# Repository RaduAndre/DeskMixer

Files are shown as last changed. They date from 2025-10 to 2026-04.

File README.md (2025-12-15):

# DeskMixer 🎛️

<div align="center">

A **low latency** physical volume mixer with programmable buttons for Windows, inspired by [Deej](https://github.com/omriharel/deej).

**Control your audio with near-instant response and automate actions with real hardware - fully scalable to your needs!**

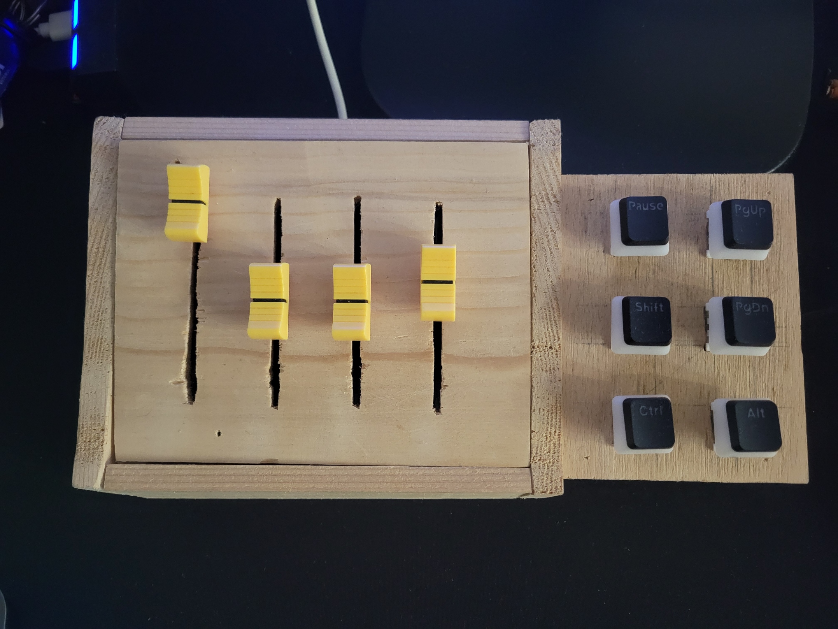
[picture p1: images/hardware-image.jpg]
DeskMixer Hardware


[Features](#-features) • [Hardware](#-hardware) • [Installation](#-installation) • [Configuration](#-configuration) • [Building](#-building-from-source)

</div>

---

## 🚀 Get Started 

**For Windows users, the simplest way to get up and running is with the pre-compiled executable!**

1.  **Download:** Go to the [**Releases Page**](/RaduAndre/DeskMixer/releases) and download the latest `DeskMixer.exe` file. (no instalation needed)
2. **Configure:** Follow the steps in the [Configuration](#-configuration) section to bind your sliders and program your buttons!

---

## 📸 Gallery

### Modern Software Interface

DeskMixer features a sleek, modern interface with a dark theme and smooth animations designed for intuitive hardware control.

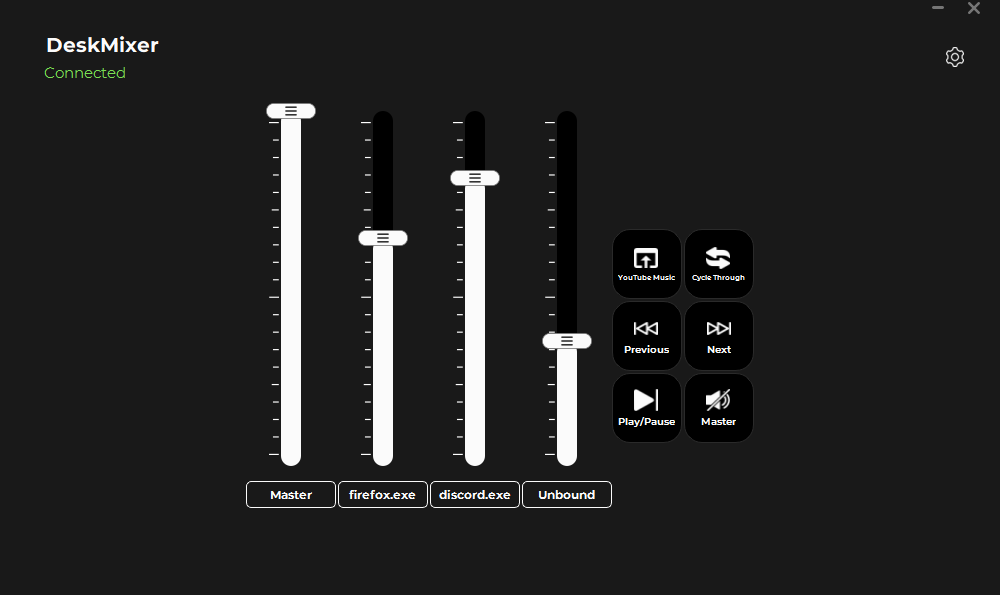
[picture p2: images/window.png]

*Clean, modern interface with volume sliders and programmable action buttons*

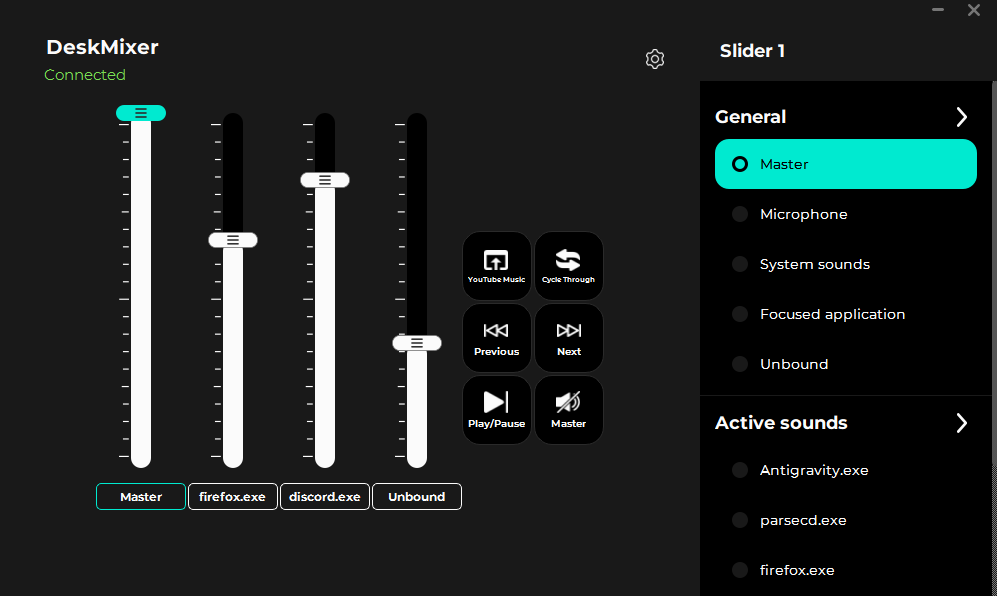
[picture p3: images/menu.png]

*Sliding configuration menu for easy customization*

#### Interface Features

**Visual Design:**
- 🎨 **Modern Interface**: Premium glassmorphic design with **customizable accent colors** and animations
- 🪟 **Frameless Window**: Custom title bar with drag-to-move functionality
- 📐 **Scalable Layout**: Automatically adapts to any number of sliders and buttons
- ✨ **Smooth Animations**: Fluid transitions and visual feedback for all interactions

**Volume Sliders:**
- 🎛️ **Visual Scale Indicators**: Each slider displays a scale icon showing the full range
- 🏷️ **Smart Labels**: Automatically display bound applications (e.g., "Master + Spotify")
- 💚 **Hardware Sync**: Sliders animate smoothly when adjusted via hardware with green highlight feedback
- 🔄 **Drag-and-Drop Reordering**: Rearrange sliders to match your preferred layout
- 🖱️ **Click-to-Configure**: Click any slider to open its configuration menu

**Action Buttons:**
- 🎮 **Customizable Grid**: Arrange buttons in any grid size (rows × columns)
- 🔵 **Active State Indicators**: Blue highlight shows which buttons are configured
- ⚡ **Hardware Feedback**: Buttons flash when pressed on the physical device
- 🔄 **Drag-and-Drop**: Reorder buttons including empty placeholder positions
- 📝 **Dynamic Labels**: Button text adjusts to show the configured action

**Configuration Menu:**
- 📱 **Sliding Panel**: Smooth slide-in menu from the right side
- 🎯 **Context-Sensitive**: Different menus for sliders, buttons, and settings
- 🔍 **Live Search**: Browse and add applications with file picker integration
- 📋 **Expandable Sections**: Organized categories with collapsible headers
- ✅ **Visual Selection**: Active bindings highlighted with checkmarks

**Settings & Customization:**
- ⚙️ **General Settings**: Start hidden, Windows startup integration, slider sampling modes
- 📐 **Layout Controls**: Configure button grid dimensions (R×C)
- 🔄 **Reorder Modes**: Toggle swap modes for buttons or sliders independently
- 📊 **Slider Sampling**: Choose between Soft, Normal, or Hard sensitivity modes
- ℹ️ **Version Display**: Build version shown at bottom of settings menu

**Hardware Integration:**
- 🔌 **Real-time Sync**: Slider positions update instantly from hardware movements
- 🎯 **Button Press Feedback**: Visual flash confirms hardware button presses
- 🔄 **Bidirectional Control**: Changes sync between hardware and software
- 🚫 **Read-only Sliders**: UI sliders display-only to prevent conflicts with hardware control

### DIY Hardware Build
DeskMixer Hardware
*A functional, handcrafted build - proving that professional results don't require a professional workshop!*

---

## ✨ Features

DeskMixer takes physical volume control and supercharges it with macro-like button actions.

### Volume Control
- ⚡ **Low Latency**: Optimized for near-instant response (~10-20ms) with 115200 baud serial communication
- 🎛️ **Physical Sliders**: Control individual application volumes with real hardware sliders
- 📊 **Scalable Design**: Add as many sliders as you need - the software adapts automatically
- 🔊 **Flexible Targets**: Control master volume, microphone, system sounds, or individual apps
- 🎚️ **Adjustable Sensitivity**: Choose between Instant, Responsive, Soft, Normal, or Hard sampling modes
- 💾 **Persistent Settings**: Your configuration is saved between sessions

### Button Actions
- ⌨️ **Custom Keybinds**: Map any keyboard shortcut to physical buttons
- 🎮 **Media Controls**: Play/pause, next/previous track, seek forward/backward
- 🔇 **Mute Controls**: Instant mute/unmute for system, microphone, or specific applications
- 🔀 **Audio Switching**: Switch between audio output devices with a button press
- 🚀 **App Launcher**: Launch or focus applications instantly

### System Integration
- 🪟 **System Tray**: Runs minimized with quick access
- 🔌 **Auto-Detection**: Automatic serial port detection
- 🔄 **Hot-Reload**: Configuration updates in real-time
- 🎯 **Focus Tracking**: Optional control of currently active application

---

## 🎛️ Volume Targets

The software supports multiple volume control modes:

| Target | Description | Use Case |
|---|---|---|
| 🔊 **Master** | System master volume | Overall volume control |
| 🎤 **Microphone** | Default microphone input | Quick mic adjustments |
| 🔔 **System Sounds** | Windows notification sounds | Silence those pings! |
| ⭐ **Current Application** | Currently focused app | Dynamic control of active app |
| 🎵 **Individual Apps** | Specific applications | Dedicated controls (Spotify, Discord, etc.) |
| ❔ **Unbound** | No assignment | Flexible unassigned slider |
| ❌ **None** | Disabled | Slider inactive |

**Note:** The application list updates automatically based on running audio applications. **The UI scales to accommodate any number of slider bindings you create!**

---

## 🎮 Button Actions

### Media Controls
- ⏯️ **Play/Pause**: Toggle media playback
- ⏭️ **Next Track**: Skip to next media track  
- ⏮️ **Previous Track**: Go to previous media track
- ⏩ **Seek Forward**: Jump forward in current media
- ⏪ **Seek Backward**: Jump backward in current media

### Audio Controls
- 🔊 **Volume Up**: Increase system volume
- 🔉 **Volume Down**: Decrease system volume
- 🔇 **Mute**: Toggle mute for system, microphone, or specific application
- 🔀 **Switch Audio Output**: Switch between available audio output devices*

### Advanced Actions
- ⌨️ **Custom Keybind**: Execute any keyboard shortcut (see [KEYBIND_EXAMPLES.md](KEYBIND_EXAMPLES.md))
- 🚀 **Launch App**: Start or focus specific applications

**Pro Tip:** Combine button actions with specific application targets for powerful workflows. For example:
- Mute Discord specifically with one button
- Launch Spotify and set volume to 50% with another
- Send custom shortcuts to specific apps

**The button configuration UI scales dynamically - add as many buttons as your microcontroller has pins!**

---

## 🔧 Hardware

### Required Components
- **Microcontroller**: ESP32 or compatible Arduino board
- **Sliders**: 4x 10kΩ linear potentiometers (scalable to more)
- **Buttons**: 6x push buttons (scalable to more)
- **Connection**: PCB or breadboard
- **Cable**: USB cable for serial communication

### Default Pin Configuration
You can modify these in the Arduino sketch to match your build:

**Sliders:**
- GPIO 33, 32, 35, 34

**Buttons:**
- GPIO 27, 25, 14, 26, 12, 13

### Expanding Your Build
Want more controls? Simply:
1. Add more potentiometers/buttons to your hardware
2. Update the pin configuration in `arduino/DeskMixer/DeskMixer.ino`
3. Upload the modified firmware
4. The DeskMixer software will automatically detect and configure the new inputs!

### Circuit Explanation

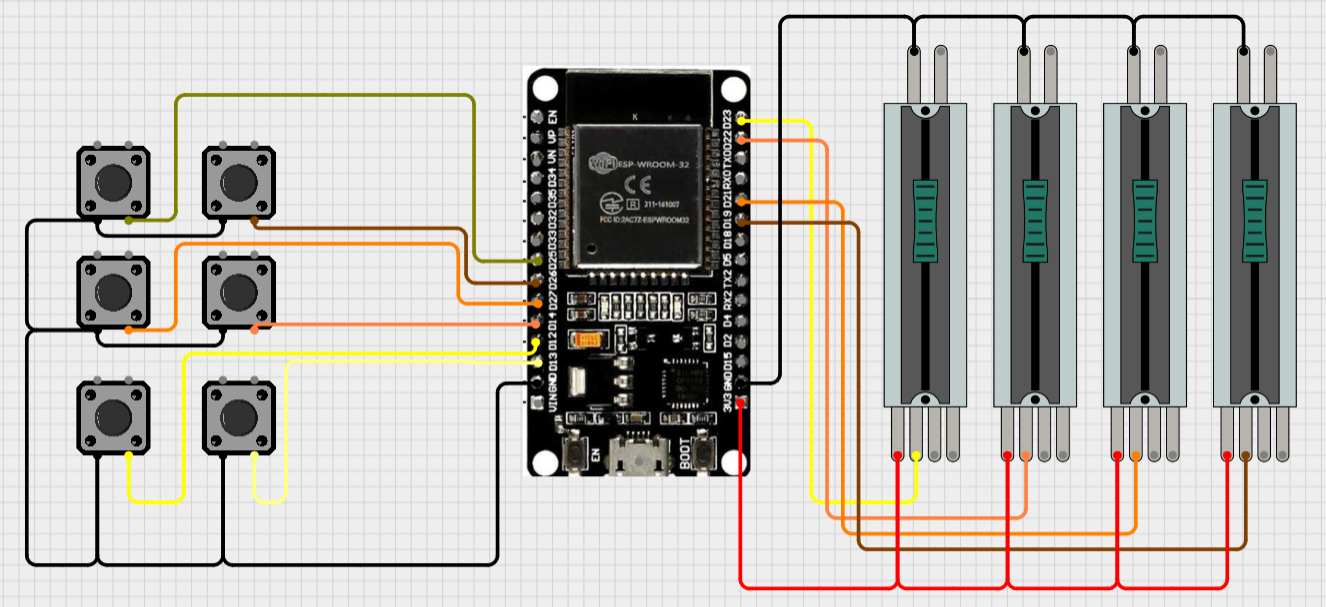
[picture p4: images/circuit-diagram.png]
Circuit Diagram

*Wiring diagram showing connections between ESP32, potentiometers, and buttons*

#### Understanding the Circuit

The DeskMixer circuit consists of three main components working together:

**Power Distribution:**
- The ESP32 is powered via USB connection to your computer
- All components share a common ground (GND) connection
- The 3.3V pin from the ESP32 powers the potentiometers

**Potentiometer Connections (Volume Sliders):**
Each potentiometer has three pins:
- **Left pin**: Connected to GND (ground)
- **Middle pin (wiper)**: Connected to ESP32 analog input pins (GPIO 33, 32, 35, 34)
- **Right pin**: Connected to 3.3V power

As you move the slider, the middle pin voltage varies between 0V and 3.3V, which the ESP32 reads as analog values (0-1024). The software then maps these values to volume levels (0-100%).

**Button Connections:**
Each button uses a simple pull-down configuration:
- **One side**: Connected to ESP32 digital input pins (GPIO 27, 25, 14, 26, 12, 13)
- **Other side**: Connected to GND (ground)
- **Internal pull-up resistor**: Enabled in firmware (button reads HIGH when not pressed, LOW when pressed)

**Color Coding in Diagram:**
- **Black**: Ground connections
- **Red**: 3.3V power connections
- **Yellow/Orange/Blue**: Signal wires to ESP32 GPIO pins

#### Important Notes

⚠️ **Analog Pin Limitations**: On ESP32, not all pins support analog reading. Use only ADC1 pins (GPIO 32-39) for potentiometers. Avoid GPIO 25 and 26 for analog input as they're DAC pins.

⚠️ **Voltage Levels**: ESP32 GPIO pins are 3.3V tolerant. Never connect 5V directly to any GPIO pin.

💡 **Wire Gauge**: Use 22-24 AWG wire for connections. Solid core wire works well for breadboard prototyping, while stranded wire is better for the final build.

💡 **Debouncing**: The firmware includes software debouncing for buttons to prevent false triggers. No additional hardware debouncing (capacitors) is needed.

### 3D Models & PCB Files
> **Coming Soon**: 3D printable enclosure models and Gerber files for PCB manufacturing will be added in future updates!

---

## 📦 Installation

### Option 1: Pre-built Executable (Easiest)

1. Download `DeskMixer.exe` from the [Releases](https://github.com/RaduAndre/DeskMixer/releases) page.
2. Run the executable

### Option 2: Run from Source

**Requirements:**
- Python 3.13+
- Arduino IDE
- ESP32 board or compatible Arduino

**Steps:**

1. Clone the repository:
```bash
git clone https://github.com/RaduAndre/DeskMixer.git
cd DeskMixer/src
```

2. Install dependencies:
```bash
pip install -r requirements.txt
```

3. Run the application:
```bash
python main.py
```

### Upload Firmware to Arduino

1. Open `arduino/DeskMixer/DeskMixer.ino` in Arduino IDE
2. Select your board (ESP32) and COM port
3. Upload the sketch
4. The firmware will automatically communicate with DeskMixer

---

## ⚙️ Configuration

### First-Time Setup

1. **Launch DeskMixer**
2. **Connect Hardware**: The application will automatically detect your Arduino's serial port
3. **Configure Sliders**: 
   - Click on any slider to open the configuration menu
   - Select from General options (Master, Microphone, System sounds, Focused application, Unbound)
   - Or choose from Active sounds (currently running applications)
   - Or add custom applications via the search function
   - Multiple applications can be bound to the same slider
4. **Configure Buttons**:
   - Click on any button to open the action menu
   - Select from Media Controls (Play/Pause, Next, Previous, etc.)
   - Configure Mute actions with specific targets
   - Set up custom Keybinds or Launch app actions
   - Changes save automatically

### Slider Configuration

**Binding Options:**
- **General Targets**: Master volume, Microphone, System sounds, Focused application, Unbound
- **Active Sounds**: Dynamically detected running applications with audio
- **Custom Applications**: Add any application via name search or file browser
- **Multiple Bindings**: Bind multiple applications to a single slider for grouped control
- **Smart Labels**: Slider labels automatically update to show all bound applications

**Configuration Menu:**
- Click any slider to open its dedicated configuration menu
- Expandable sections organize options by category
- Active bindings show checkmarks for easy identification
- Right-click custom applications to delete them from the list
- Browse for .exe or .lnk files to add new applications

### Button Configuration

**Available Actions:**

*Media Controls:*
- Play/Pause, Previous, Next
- Volume up/down
- Seek backward/forward

*Advanced Actions:*
- **Mute**: Choose target (Master, Microphone, System sounds, Focused application)
- **Switch Audio Output**: Cycle through devices or select specific output (Speakers, Headphones)
- **Keybind**: Enter custom keyboard shortcuts (see [KEYBIND_EXAMPLES.md](KEYBIND_EXAMPLES.md))
- **Launch app**: Browse and select applications to launch or focus

**Configuration Menu:**
- Click any button to open its action menu
- Expandable items reveal sub-options (e.g., Mute → Master/Microphone/etc.)
- Input fields for Keybind and Launch app actions
- File browser integration for selecting applications
- Active action highlighted with blue indicator

### Layout Customization

**Button Grid:**
- Open Settings menu (gear icon)
- Navigate to Layout → Grid Size
- Enter desired Rows (R) and Columns (C)
- Grid automatically validates against available buttons
- Invalid dimensions flash red with error feedback

**Reordering Elements:**
- Open Settings → Layout → Reorder Elements
- Select "Swap Buttons" or "Swap Sliders" to enter reorder mode
- Drag and drop elements to rearrange them
- Supports sparse layouts (buttons can occupy any grid position)
- Click the reorder option again to exit reorder mode

### Settings Menu

Access via the gear icon in the top-right corner:

**General:**
- **Start Hidden (on tray)**: Launch minimized to system tray
- **Start on Windows startup**: Automatically launch with Windows
- **Slider Sampling**: Adjust hardware response sensitivity
  - **Instant**: Zero-latency mode - no smoothing for immediate response
  - **Responsive**: Minimal smoothing - very fast with slight stabilization
  - **Soft**: Light averaging - balanced response (5 samples)
  - **Normal**: Moderate averaging - smooth control (10 samples)
  - **Hard**: Heavy averaging - very smooth, slower response (20 samples)

**Layout:**
- **Grid Size**: Configure button grid dimensions
- **Accent Color**: Customize the UI with 'Default' (Teal) or any custom color via the picker
- **Reorder Elements**: Enable drag-and-drop for buttons or sliders

### System Tray
- **Double-click** tray icon: Show/hide main window
- **Right-click** tray icon: Quick actions menu
- Window automatically minimizes to tray when closed

---

## 🏗️ Building from Source

Create your own executable using either method:

### PyInstaller (Faster)
```bash
cd src
python build_app.py
```

### Nuitka (More Optimized)
```bash
cd src
python build_nuitka.py
```

Built executables will appear in `src/build/dist/`

---

## 🎨 About the Hardware Build

The device shown in the gallery was handcrafted with basic tools and materials - no fancy workshop required! It's a testament that functional, effective hardware doesn't need to be professionally manufactured. The beauty of this project is in its functionality and the satisfaction of building something yourself.

**DIY Philosophy:** This project embraces the maker spirit - it's about creating tools that work for YOU, not winning beauty contests. If it controls your volume and makes your workflow better, it's perfect.

---

## 🛠️ Customization & Scalability

DeskMixer is designed to grow with your needs:

### Hardware Scaling
- **Start small**: 2 sliders and 2 buttons  
- **Go big**: 16+ sliders and 20+ buttons
- **Mix it up**: Combine sliders, buttons, rotary encoders, or other inputs

The software automatically adapts to whatever hardware configuration you define in the Arduino firmware!

### Software Flexibility
- Configure targets per-slider/button
- Create complex automation chains
- Save multiple profiles (future feature)

---

## 📝 Keybind Examples

For comprehensive keybind examples and syntax, see [KEYBIND_EXAMPLES.md](KEYBIND_EXAMPLES.md)

---

## 🤝 Contributing

Contributions are welcome! Whether it's:
- 🐛 Bug reports
- 💡 Feature suggestions  
- 📝 Documentation improvements
- 🔧 Code contributions
- 📸 Sharing your build

Feel free to open an issue or submit a pull request!

---

## 📄 License

This project is open source. Check the [LICENSE](LICENSE) file for details.

---

## 🙏 Acknowledgments

- Inspired by [Deej](https://github.com/omriharel/deej) by Omri Harel
- Built with passion for makers and tinkerers everywhere
- Special thanks to everyone who builds DIY hardware and shares their projects!

---

## 📞 Support

- **Issues**: [GitHub Issues](https://github.com/RaduAndre/DeskMixer/issues)
- **Discussions**: [GitHub Discussions](https://github.com/RaduAndre/DeskMixer/discussions)

---

<div align="center">

**Made with 🎛️ by makers, for makers**

Star ⭐ this repo if you find it useful! You can also support further development [buying me a Coffe ☕](https://ko-fi.com/andreiradu).

</div>

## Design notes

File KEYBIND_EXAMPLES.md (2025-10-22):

# Keybind Examples

When using the "Keybind (Custom)" action, you can specify various key combinations:

## Single Keys
- `a`, `b`, `c`, etc.
- `space`
- `enter`
- `esc`

## Media Keys
- `play/pause media`
- `next track`
- `previous track`
- `volume up`
- `volume down`

## Key Combinations
- `ctrl+c` - Copy
- `ctrl+v` - Paste
- `alt+tab` - Switch windows
- `win+d` - Show desktop
- `ctrl+shift+esc` - Task Manager

## Special Keys
- `f1` through `f12` - Function keys
- `home`, `end`, `page up`, `page down`
- `up`, `down`, `left`, `right` - Arrow keys
- `backspace`, `delete`, `tab`

## Multiple Keys in Sequence
Use a list format: `["ctrl+c", "ctrl+v"]` to press multiple keys in order

Note: Requires 'keyboard' module to be installed for keybind functionality.

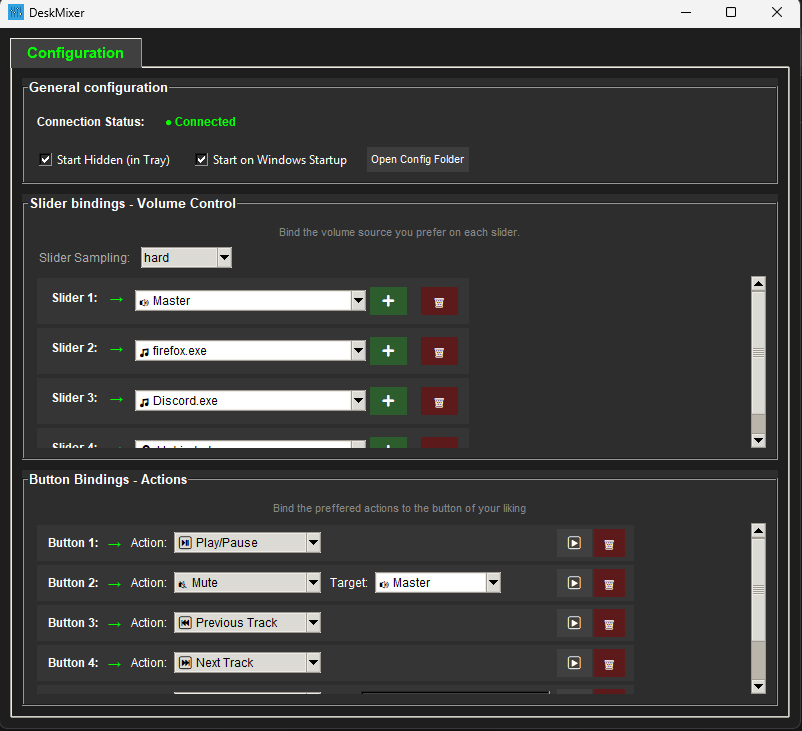
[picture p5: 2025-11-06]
images/ui-screenshot.png

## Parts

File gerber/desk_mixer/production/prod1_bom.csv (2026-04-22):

Designator | Footprint | Quantity | Value | LCSC Part #
C1, C14, C15, C16, C17, C18, C19, C2, C21, C3, C4, C6, C9 | C0603 | 13 | 100n | C14663
C10, C11 | C0603 | 2 | 10p | C1634
C12, C13 | C0805 | 2 | 22u | C602037
C20 | CAP-SMD_BD10.0-L10.3-W10.3-FD | 1 | BXJ 10V1000uF | C165632
C5 | C0603 | 1 | 10u | C19702
C7, C8 | C0603 | 2 | 1uF | C15849
CN1, CN2 | CONN-SMD_4P-P1.00_SM04B-SRSS-TB-LF-SN | 2 | SM04B-SRSS-TB (LF)(SN) | C160404
D1 | screen | 1 | ~
D2 | SMA_L4.2-W2.6-LS5.0-RD_1 | 1 | SS14 | C2480
KAL1, KAL2, KAL3, KAL4, KAL5, KAL6 | TH_L10.9-W5.9-CPG151101S11-2 | 6 | CPG151101S11-2_C49352235 | C49352235
L1 | L0603 | 1 | Ferritebead | C85831
LED1, LED10, LED11, LED12, LED13, LED14, LED15, LED16, LED17, LED18, LED19, LED2, LED20, LED21, LED22, LED23, LED24, LED25, LED26, LED27, LED28, LED29, LED3, LED30, LED31, LED32, LED33, LED34, LED35, LED36, LED37, LED38, LED39, LED4, LED40, LED41, LED42, LED43, LED44, LED45, LED46, LED5, LED6, LED7, LED8, LED9 | LED-SMD_4P-L3.7-W3.5-P1.75-BR-SK6812MINI | 46 | SK6812MINI | C2886570
LED47 | LED0805-R-RD_RED | 1 | Red led | C19171391
R1, R2 | R0603 | 2 | 5.1k | C2907044
R3 | R0603 | 1 | 10k | C98220
R4, R5 | R0805 | 2 | 1.5k | C336856
S1, S2, S3, S4, S5 | b103 | 5 | ~
SW1 | SW-SMD_MST-12D18G4-SPDT-SLIDE-SWITCH | 1 | MST-12D18G4 SPDT SLIDE SWITCH | C49023767
U1 | LQFP-48_L7.0-W7.0-P0.50-LS9.0-BL | 1 | STM32F103C8T6 | C8734
U2 | HDR-TH_4P-P2.54-V-M-1 | 1 | 2.54-1*4 | C5116483
U3 | SOT-223-3_L6.5-W3.4-P2.30-LS7.0-BR | 1 | AMS1117-3.3 | C6186
U4 | SOP-8_L5.3-W5.3-P1.27-LS8.0-BL | 1 | GD25Q64ESIG | C2685734
U5 | SOIC-14_L8.7-W3.9-P1.27-LS6.0-BL | 1 | SN74AHCT125DR | C155176
USB1 | USB-SMD-LIGHTNING_USB-PG | 1 | USB-PG 10PIN 040 | C2858295
X1 | CRYSTAL-SMD_4P-L3.2-W2.5-BL | 1 | X322516MMB4SI | C112972

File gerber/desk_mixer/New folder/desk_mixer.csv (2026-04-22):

Reference | Qty | Value | DNP | Exclude from BOM | Exclude from Board | Footprint | Datasheet | LCSC Part
C1,C2,C3,C4,C6,C9,C14,C15,C16,C17,C18,C19,C21 | 13 | 100n |  |  |  | LCSC_Library:C0603 | https://lcsc.com/product-detail/Multilayer-Ceramic-Capacitors-MLCC-SMD-SMT_100nF-104-10-50V_C14663.html | C14663
C5 | 1 | 10u |  |  |  | LCSC_Library:C0603 | https://lcsc.com/product-detail/Multilayer-Ceramic-Capacitors-MLCC-SMD-SMT_SAMSUNG_CL10A106KP8NNNC_10uF-106-10-10V_C19702.html | C19702
C7,C8 | 2 | 1uF |  |  |  | LCSC_Library:C0603 | https://lcsc.com/product-detail/Multilayer-Ceramic-Capacitors-MLCC-SMD-SMT_SAMSUNG_CL10A105KB8NNNC_1uF-105-10-50V_C15849.html | C15849
C10,C11 | 2 | 10p |  |  |  | LCSC_Library:C0603 | https://lcsc.com/product-detail/Multilayer-Ceramic-Capacitors-MLCC-SMD-SMT_SAMSUNG_CL10C100JB8NNNC_10pF-100-5-50V_C1634.html | C1634
C12,C13 | 2 | 22u |  |  |  | LCSC_Library:C0805 | https://lcsc.com/product-detail/Multilayer-Ceramic-Capacitors-MLCC-SMD-SMT_Samsung-Electro-Mechanics-CL21A226MAYNNNE_C602037.html | C602037
C20 | 1 | 1000uF |  |  |  | LCSC_Library:CAP-TH_BD12.5-P5.00-D0.6-FD | https://lcsc.com/product-detail/Aluminum-Electrolytic-Capacitors-Leaded_Rubycon_35YXJ1000M12-5X20_1000uF-35V_C88743.html | C88743
CN1,CN2 | 2 | SM04B-SRSS-TB (LF)(SN) |  |  |  | LCSC_Library:CONN-SMD_4P-P1.00_SM04B-SRSS-TB-LF-SN | https://lcsc.com/product-detail/Others_JST-Sales-America__JST-Sales-America-SM04B-SRSS-TB-LF-SN_C160404.html | C160404
D1 | 1 | ~ |  |  |  | sliding_potentiometer_b103:screen
D2 | 1 | SS14 |  |  |  | LCSC_Library:SMA_L4.2-W2.6-LS5.0-RD_1 | https://lcsc.com/product-detail/Schottky-Barrier-Diodes-SBD_SS14_C2480.html | C2480
Kal1,Kal2,Kal3,Kal4,Kal5,Kal6 | 6 | CPG151101S11-2_C49352235 |  |  |  | LCSC_Library:TH_L10.9-W5.9-CPG151101S11-2 |  | C49352235
L1 | 1 | Ferritebead |  |  |  | LCSC_Library:L0603 | https://lcsc.com/product-detail/Ferrite-Beads-And-Chips_muRata_BLM18KG121TN1D_120R-25-at100MHz_C85831.html | C85831
LED1,LED2,LED3,LED4,LED5,LED6,LED7,LED8,LED9,LED10,LED11,LED12,LED13,LED14,LED15,LED16,LED17,LED18,LED19,LED20,LED21,LED22,LED23,LED24,LED25,LED26,LED27,LED28,LED29,LED30,LED31,LED32,LED33,LED34,LED35,LED36,LED37,LED38,LED39,LED40,LED41,LED42,LED43,LED44,LED45,LED46 | 46 | SK6812MINI |  |  |  | LCSC_Library:LED-SMD_4P-L3.7-W3.5-P1.75-BR-SK6812MINI |  | C2886570
LED47 | 1 | Red led |  |  |  | LCSC_Library:LED0805-R-RD_RED |  | C19171391
R1,R2 | 2 | 5.1k |  |  |  | LCSC_Library:R0603 |  | C2907044
R3 | 1 | 10k |  |  |  | LCSC_Library:R0603 | https://lcsc.com/product-detail/Chip-Resistor-Surface-Mount_10KR-1_C98220.html | C98220
R4,R5 | 2 | 1.5k |  |  |  | LCSC_Library:R0805 | https://lcsc.com/product-detail/Others_PANASONIC-ERJ6RBD1501V_C336856.html | C336856
S1,S2,S3,S4,S5 | 5 | ~ |  |  |  | sliding_potentiometer_b103:b103
SW1 | 1 | MST-12D18G4 SPDT SLIDE SWITCH |  |  |  | LCSC_Library:SW-SMD_MST-12D18G4-SPDT-SLIDE-SWITCH |  | C49023767
U1 | 1 | STM32F103C8T6 |  |  |  | LCSC_Library:LQFP-48_L7.0-W7.0-P0.50-LS9.0-BL | https://lcsc.com/product-detail/ST-Microelectronics_STMicroelectronics_STM32F103C8T6_STM32F103C8T6_C8734.html | C8734
U2 | 1 | 2.54-1*4 |  |  |  | LCSC_Library:HDR-TH_4P-P2.54-V-M-1 |  | C5116483
U3 | 1 | AMS1117-3.3 |  |  |  | LCSC_Library:SOT-223-3_L6.5-W3.4-P2.30-LS7.0-BR | https://lcsc.com/product-detail/Low-Dropout-Regulators-LDO_AMS_AMS1117-3-3_AMS1117-3-3_C6186.html | C6186
U4 | 1 | GD25Q64ESIG |  |  |  | LCSC_Library:SOP-8_L5.3-W5.3-P1.27-LS8.0-BL |  | C2685734
U5 | 1 | SN74AHCT125DR |  |  |  | LCSC_Library:SOIC-14_L8.7-W3.9-P1.27-LS6.0-BL | https://lcsc.com/product-detail/74-Series_TI_SN74AHCT125DR_SN74AHCT125DR_C155176.html | C155176
USB1 | 1 | USB-PG 10PIN 040 |  |  |  | LCSC_Library:USB-SMD-LIGHTNING_USB-PG |  | C2858295
X1 | 1 | X322516MMB4SI |  |  |  | LCSC_Library:CRYSTAL-SMD_4P-L3.2-W2.5-BL | https://lcsc.com/product-detail/SMD-Crystals_16MHz-10PF_C112972.html | C112972

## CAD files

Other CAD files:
3d_model/deskmixer.FCStd

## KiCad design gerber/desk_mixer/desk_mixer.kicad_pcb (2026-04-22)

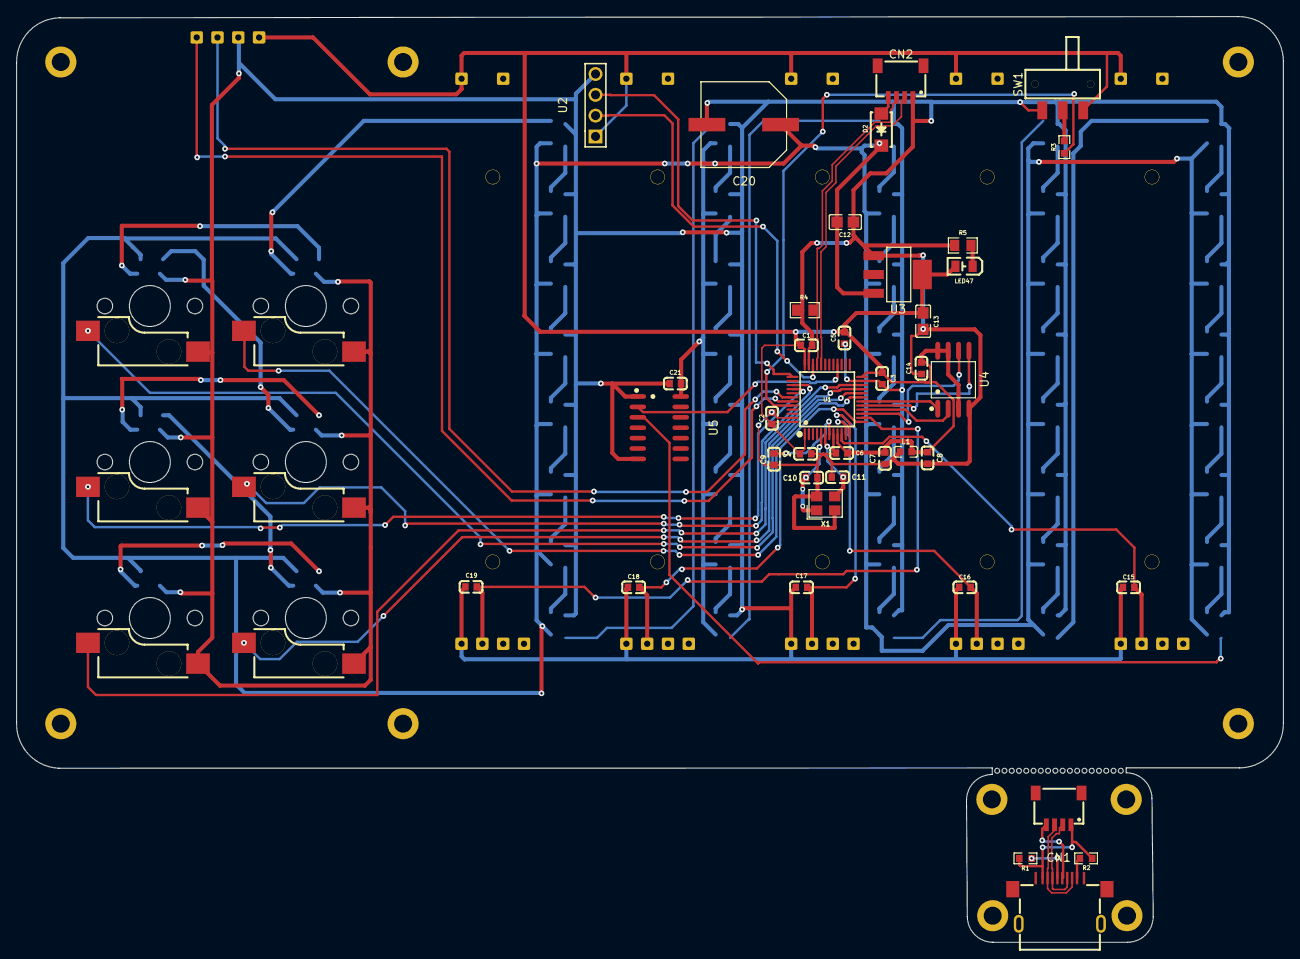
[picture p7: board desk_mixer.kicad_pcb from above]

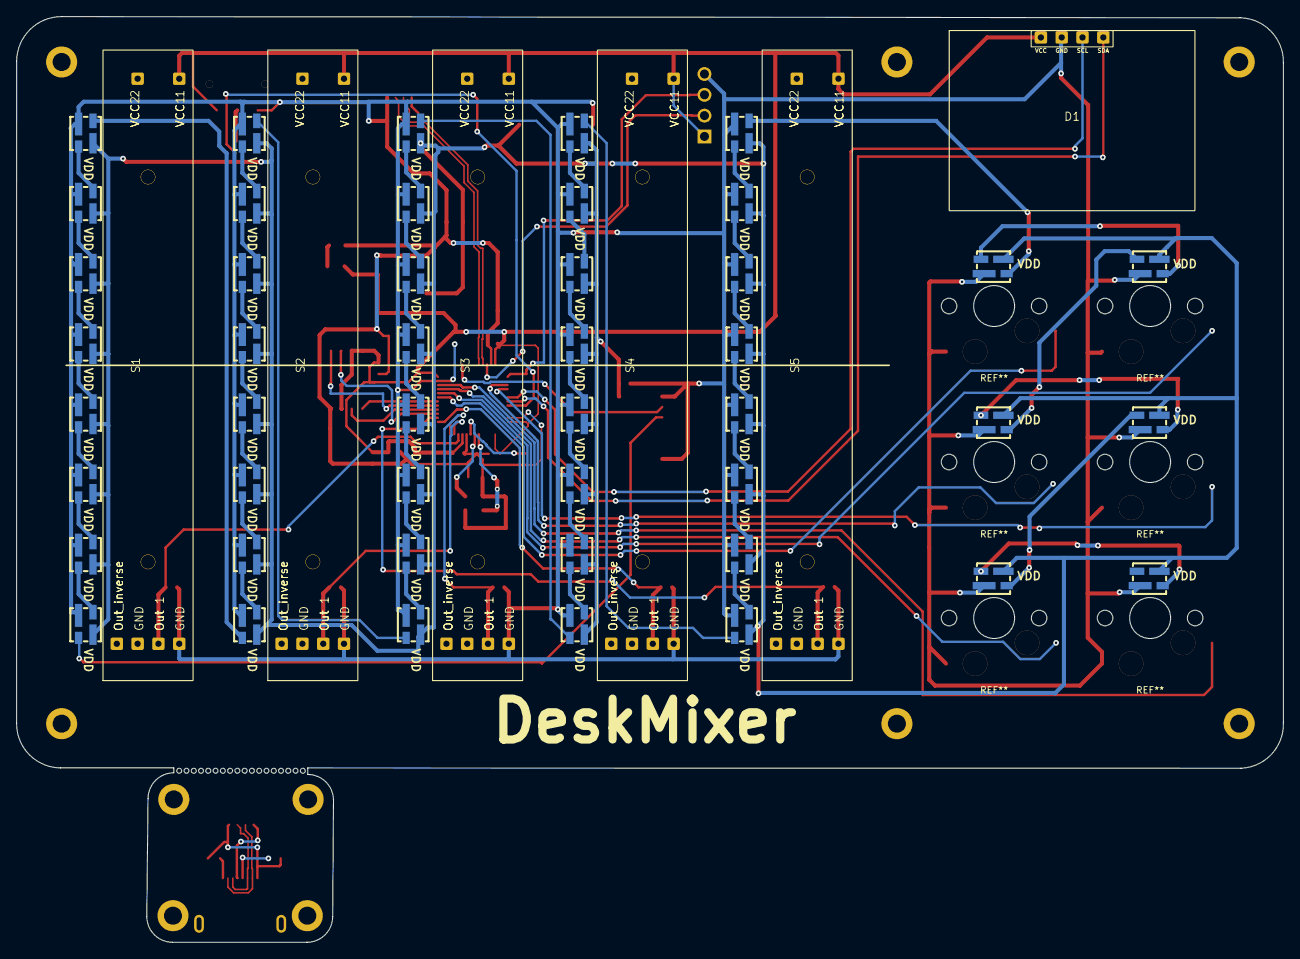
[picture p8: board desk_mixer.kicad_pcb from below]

Board: 2 copper layers, 154.7 x 113.0 mm, 97 parts (52 on the bottom side), 84 nets.

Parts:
C1, C2, C3, C4, C6, C9, C14, C15, C16, C17, C18, C19, C21: 100n; C0603
C5: 10u; C0603
C7, C8: 1uF; C0603
C10, C11: 10p; C0603
C12, C13: 22u; C0805
C20: BXJ 10V1000uF; CAP-SMD_BD10.0-L10.3-W10.3-FD
CN1, CN2: SM04B-SRSS-TB (LF)(SN); CONN-SMD_4P-P1.00_SM04B-SRSS-TB-LF-SN
D1: screen
D2: SS14; SMA_L4.2-W2.6-LS5.0-RD_1
Kal1, Kal2, Kal3, Kal4, Kal5, Kal6: CPG151101S11-2_C49352235; TH_L10.9-W5.9-CPG151101S11-2
L1: Ferritebead; L0603
LED1, LED2, LED3, LED4, LED5, LED6, LED7, LED8, LED9, LED10, LED11, LED12, LED13, LED14, LED15, LED16, LED17, LED18, LED19, LED20, LED21, LED22, LED23, LED24, LED25, LED26, LED27, LED28, LED29, LED30, LED31, LED32, LED33, LED34, LED35, LED36, LED37, LED38, LED39, LED40, LED41, LED42, LED43, LED44, LED45, LED46: SK6812MINI; LED-SMD_4P-L3.7-W3.5-P1.75-BR-SK6812MINI
LED47: Red led; LED0805-R-RD_RED
R1, R2: 5.1k; R0603
R3: 10k; R0603
R4, R5: 1.5k; R0805
S1, S2, S3, S4, S5: b103
SW1: MST-12D18G4 SPDT SLIDE SWITCH; SW-SMD_MST-12D18G4-SPDT-SLIDE-SWITCH
U1: STM32F103C8T6; LQFP-48_L7.0-W7.0-P0.50-LS9.0-BL
U2: 2.54-1*4; HDR-TH_4P-P2.54-V-M-1
U3: AMS1117-3.3; SOT-223-3_L6.5-W3.4-P2.30-LS7.0-BR
U4: GD25Q64ESIG; SOP-8_L5.3-W5.3-P1.27-LS8.0-BL
U5: SN74AHCT125DR; SOIC-14_L8.7-W3.9-P1.27-LS6.0-BL
USB1: USB-PG 10PIN 040; USB-SMD-LIGHTNING_USB-PG
X1: X322516MMB4SI; CRYSTAL-SMD_4P-L3.2-W2.5-BL

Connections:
+3.3V: C1.2, C2.2, C3.2, C4.2, C5.2, C6.2, C7.2, C8.2, C13.1, C14.2, D1.1 (VCC), L1.2, LED47.1 (+), S1.6 (VCC1), S2.6 (VCC1), S3.6 (VCC1), S4.6 (VCC1), S5.6 (VCC1), SW1.1, U1.1 (VBAT), U1.9 (VDDA), U1.24 (VDD_1), U1.36 (VDD_2), U1.48 (VDD_3), U2.1, U3.4 (VOUT), U4.3 (WP#(IO2)), U4.7 (HOLD#(IO3)), U4.8 (VCC)
/ACC1: R1.2, USB1.5 (ACC1)
/ACC2: R2.2, USB1.9 (ACC2)
/Button_1: Kal1.1, U1.19 (PB1)
/Button_2: Kal2.1, U1.20 (PB2)
/Button_3: Kal3.1, U1.39 (PB3)
/Button_4: Kal4.1, U1.40 (PB4)
/Button_5: Kal5.1, U1.21 (PB10)
/Button_6: Kal6.1, U1.22 (PB11)
/D+: CN1.3, USB1.3 (DP1), USB1.8 (DP2)
/D-: CN1.2, USB1.4 (DN1), USB1.7 (DN2)
/GPIO out: U1.18 (PB0), U4.1 (~CS)
/LED_CMD 3.3v: U1.28 (PB15), U5.2 (1A)
/LED_CMD 5v: LED1.1 (DIN), U5.3 (1Y)
/MISO: U1.16 (PA6), U4.2 (SO(IO1))
/MOSI: U1.17 (PA7), U4.5 (SI(IO0))
/NRST: C9.1, U1.7 (NRST)
/OSC_IN: C10.1, U1.5 (PD0-OSC_IN), X1.1 (OSC1)
/OSC_OUT: C11.1, U1.6 (PD1-OSC_OUT), X1.3 (OSC2)
/SCK: U1.15 (PA5), U4.6 (SCLK)
/SLIDER_1: C15.1, S1.3 (Out), U1.10 (PA0-WKUP)
/SLIDER_2: C16.1, S2.3 (Out), U1.11 (PA1)
/SLIDER_3: C17.1, S3.3 (Out), U1.12 (PA2)
/SLIDER_4: C18.1, S4.3 (Out), U1.13 (PA3)
/SLIDER_5: C19.1, S5.3 (Out), U1.14 (PA4)
/SW Boot: R3.1, U1.44 (BOOT0)
/SWIDO: U1.34 (PA13), U2.2
/USB_D+: CN2.3, R4.2, U1.33 (PA12)
/USB_D-: CN2.2, U1.32 (PA11)
GND: C1.1, C2.1, C3.1, C4.1, C5.1, C6.1, C7.1, C8.1, C9.2, C10.2, C11.2, C12.2, C13.2, C14.1, C15.2, C16.2, C17.2, C18.2, C19.2, C20.2, C21.2, CN2.1, D1.2 (GND), Kal1.2, Kal2.2, Kal3.2, Kal4.2, Kal5.2, Kal6.2, L1.1, LED1.4 (GND), LED2.4 (GND), LED3.4 (GND), LED4.4 (GND), LED5.4 (GND), LED6.4 (GND), LED7.4 (GND), LED8.4 (GND), LED9.4 (GND), LED10.4 (GND), LED11.4 (GND), LED12.4 (GND), LED13.4 (GND), LED14.4 (GND), LED15.4 (GND), LED16.4 (GND), LED17.4 (GND), LED18.4 (GND), LED19.4 (GND), LED20.4 (GND), LED21.4 (GND), LED22.4 (GND), LED23.4 (GND), LED24.4 (GND), LED25.4 (GND), LED26.4 (GND), LED27.4 (GND), LED28.4 (GND), LED29.4 (GND), LED30.4 (GND), LED31.4 (GND), LED32.4 (GND), LED33.4 (GND), LED34.4 (GND), LED35.4 (GND), LED36.4 (GND), LED37.4 (GND), LED38.4 (GND), LED39.4 (GND), LED40.4 (GND), LED41.4 (GND), LED42.4 (GND), LED43.4 (GND), LED44.4 (GND), LED45.4 (GND), LED46.4 (GND), R4.1, R5.1, S1.4 (GND), S2.4 (GND), S3.4 (GND), S4.4 (GND), S5.4 (GND), SW1.3, U1.8 (VSSA), U1.23 (VSS_1), U1.35 (VSS_2), U1.47 (VSS_3), U2.4, U3.1 (GND), U4.4 (VSS), U5.1 (~1OE), U5.7 (GND), X1.2 (GND), X1.4 (GND)
GND2: CN1.1, R1.1, R2.1, USB1.2 (GND)
unnamed: LED1.3 (DOUT), LED2.1 (DIN)
unnamed: LED2.3 (DOUT), LED3.1 (DIN)
unnamed: LED3.3 (DOUT), LED4.1 (DIN)
unnamed: LED4.3 (DOUT), LED5.1 (DIN)
unnamed: LED5.3 (DOUT), LED6.1 (DIN)
unnamed: LED6.3 (DOUT), LED7.1 (DIN)
unnamed: LED7.3 (DOUT), LED8.1 (DIN)
unnamed: LED8.3 (DOUT), LED9.1 (DIN)
unnamed: LED9.3 (DOUT), LED10.1 (DIN)
unnamed: LED10.3 (DOUT), LED11.1 (DIN)
unnamed: LED11.3 (DOUT), LED12.1 (DIN)
unnamed: LED12.3 (DOUT), LED13.1 (DIN)
unnamed: LED13.3 (DOUT), LED14.1 (DIN)
unnamed: LED14.3 (DOUT), LED15.1 (DIN)
unnamed: LED15.3 (DOUT), LED16.1 (DIN)
unnamed: LED16.3 (DOUT), LED17.1 (DIN)
unnamed: LED17.3 (DOUT), LED18.1 (DIN)
unnamed: LED18.3 (DOUT), LED19.1 (DIN)
unnamed: LED19.3 (DOUT), LED20.1 (DIN)
unnamed: LED20.3 (DOUT), LED21.1 (DIN)
unnamed: LED21.3 (DOUT), LED22.1 (DIN)
unnamed: LED22.3 (DOUT), LED23.1 (DIN)
unnamed: LED23.3 (DOUT), LED24.1 (DIN)
unnamed: LED24.3 (DOUT), LED25.1 (DIN)
unnamed: LED25.3 (DOUT), LED26.1 (DIN)
unnamed: LED26.3 (DOUT), LED27.1 (DIN)
unnamed: LED27.3 (DOUT), LED28.1 (DIN)
unnamed: LED28.3 (DOUT), LED29.1 (DIN)
unnamed: LED29.3 (DOUT), LED30.1 (DIN)
unnamed: LED30.3 (DOUT), LED31.1 (DIN)
unnamed: LED31.3 (DOUT), LED32.1 (DIN)
unnamed: LED32.3 (DOUT), LED33.1 (DIN)
unnamed: LED33.3 (DOUT), LED34.1 (DIN)
unnamed: LED34.3 (DOUT), LED35.1 (DIN)
unnamed: LED35.3 (DOUT), LED36.1 (DIN)
unnamed: LED36.3 (DOUT), LED37.1 (DIN)
unnamed: LED37.3 (DOUT), LED38.1 (DIN)
unnamed: LED38.3 (DOUT), LED39.1 (DIN)
unnamed: LED39.3 (DOUT), LED40.1 (DIN)
unnamed: LED40.3 (DOUT), LED41.1 (DIN)
unnamed: LED41.3 (DOUT), LED42.1 (DIN)
unnamed: LED42.3 (DOUT), LED43.1 (DIN)
unnamed: LED43.3 (DOUT), LED44.1 (DIN)
unnamed: LED44.3 (DOUT), LED45.1 (DIN)
unnamed: LED45.3 (DOUT), LED46.1 (DIN)
unnamed: LED47.2 (-), R5.2
unnamed: R3.2, SW1.2
SCL: D1.3 (SCl), U1.42 (PB6)
SDA: D1.4 (SDA), U1.43 (PB7)
SWCLC: U1.37 (PA14), U2.3
VBUS: C12.1, C20.1, C21.1, D2.1 (K), LED1.2 (VDD), LED2.2 (VDD), LED3.2 (VDD), LED4.2 (VDD), LED5.2 (VDD), LED6.2 (VDD), LED7.2 (VDD), LED8.2 (VDD), LED9.2 (VDD), LED10.2 (VDD), LED11.2 (VDD), LED12.2 (VDD), LED13.2 (VDD), LED14.2 (VDD), LED15.2 (VDD), LED16.2 (VDD), LED17.2 (VDD), LED18.2 (VDD), LED19.2 (VDD), LED20.2 (VDD), LED21.2 (VDD), LED22.2 (VDD), LED23.2 (VDD), LED24.2 (VDD), LED25.2 (VDD), LED26.2 (VDD), LED27.2 (VDD), LED28.2 (VDD), LED29.2 (VDD), LED30.2 (VDD), LED31.2 (VDD), LED32.2 (VDD), LED33.2 (VDD), LED34.2 (VDD), LED35.2 (VDD), LED36.2 (VDD), LED37.2 (VDD), LED38.2 (VDD), LED39.2 (VDD), LED40.2 (VDD), LED41.2 (VDD), LED42.2 (VDD), LED43.2 (VDD), LED44.2 (VDD), LED45.2 (VDD), LED46.2 (VDD), U3.3 (VIN), U5.14 (VCC)
VBUS2: CN1.4, USB1.6 (PWR)
VBUS_Z: CN2.4, D2.2 (A)

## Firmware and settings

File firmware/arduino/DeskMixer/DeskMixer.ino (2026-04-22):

// --- CONSTANTS ---
const int NUM_SLIDERS = 5;
const int NUM_BUTTONS = 6;
const int SCREEN_ACTIVE = 1;  // 1 = screen enabled, 0 = screen disabled

// ESP32 analog input pins for 5 sliders (update to match your board)
const int analogInputs[NUM_SLIDERS] = {33, 32, 35, 34, 39};
const int buttonInputs[NUM_BUTTONS] = {12, 13, 14, 26, 27, 25};

// Define the interval (in milliseconds) for sending slider data
const long SEND_INTERVAL_MS = 10;

// Button debouncing interval (in milliseconds)
const int DEBOUNCE_MS = 10;

// Handshake constants
const String HANDSHAKE_REQUEST = "DeskMixer controller request";
const String HANDSHAKE_RESPONSE = "DeskMixer Controller Ready";

// Configuration request constants
const String CONFIG_REQUEST = "GET_CONFIG";
const String CONFIG_RESPONSE = "CONFIG:SLIDERS:" + String(NUM_SLIDERS) + ":BUTTONS:" + String(NUM_BUTTONS) + ":SCREEN:" + String(SCREEN_ACTIVE);

// --- GLOBAL VARIABLES ---

// Stores the current slider values mapped to 0-1000 (= volume * 1000).
// The host divides by 1000.0 to get a float [0.0-1.0] for the audio API.
int analogSliderValues[NUM_SLIDERS];

// Stores the current state of the buttons (1 for pressed, 0 for released)
int buttonValues[NUM_BUTTONS];

// Stores the state of the buttons from the previous loop iteration (for press detection)
int previousButtonValues[NUM_BUTTONS] = {0};

// Stores the last time each button changed state (for debouncing)
unsigned long lastButtonChange[NUM_BUTTONS] = {0};

// Variable to store the last time slider data was sent
unsigned long lastSendTime = 0;

// Buffer for incoming serial data
String inputBuffer = "";


// --- SETUP ---

void setup() {
  // Initialize slider inputs
  for (int i = 0; i < NUM_SLIDERS; i++) {
    pinMode(analogInputs[i], INPUT);
  }

  // Initialize button inputs with internal pull-up resistors
  for (int i = 0; i < NUM_BUTTONS; i++) {
    pinMode(buttonInputs[i], INPUT_PULLUP);
  }

  // Set ADC resolution for consistent reading (0-1023 range for 10-bit)
  analogReadResolution(10);

  // Initialize serial communication at high speed for low latency
  Serial.begin(115200);

  // Wait for serial port to be ready
  delay(1000);

  // Send handshake response immediately on startup
  Serial.println(HANDSHAKE_RESPONSE);
}


// --- MAIN LOOP ---

void loop() {
  // 0. Check for incoming serial commands (handshake requests and config requests)
  checkSerialInput();

  // 1. Read all physical inputs
  // NOTE: This runs on every iteration of loop(), making buttons highly responsive.
  readCurrentValues();

  // 2. Check for and send one-shot button press events (separate lines, only sent on press)
  // NOTE: This runs on every iteration of loop() and bypasses the 10ms timing check.
  checkAndSendButtonEvents();

  // 3. Non-blocking check to send continuous slider data
  unsigned long currentMillis = millis();

  // Send the slider values only if the interval has passed
  if (currentMillis - lastSendTime >= SEND_INTERVAL_MS) {
    lastSendTime = currentMillis; // Save the last time the data was sent
    sendContinuousSliderValues();
  }

  // The loop is now non-blocking and will cycle as fast as possible,
  // making button detection immediate.
}


// --- SERIAL INPUT HANDLER ---

// Check for incoming serial commands (like handshake requests and config requests)
void checkSerialInput() {
  while (Serial.available() > 0) {
    char inChar = (char)Serial.read();

    if (inChar == '\n' || inChar == '\r') {
      // Process complete command
      if (inputBuffer.length() > 0) {
        processSerialCommand(inputBuffer);
        inputBuffer = "";
      }
    } else {
      // Add character to buffer
      inputBuffer += inChar;
    }
  }
}


// Process received serial commands
void processSerialCommand(String command) {
  command.trim();

  // Handle handshake request
  if (command == HANDSHAKE_REQUEST) {
    Serial.println(HANDSHAKE_RESPONSE);
  }

  // Handle configuration request
  else if (command == CONFIG_REQUEST) {
    Serial.println(CONFIG_RESPONSE);
  }

  // Future commands can be added here (e.g., LED control, configuration, etc.)
}


// --- DATA READ FUNCTION ---

// Reads the current state of all analog sliders and digital buttons.
void readCurrentValues() {
  // Read analog sliders.
  // ESP32 ADC is 10-bit (0-1023). We map to 0-1000 so the value represents
  // volume * 1000, matching the STM32 firmware behaviour.
  for (int i = 0; i < NUM_SLIDERS; i++) {
    int raw = analogRead(analogInputs[i]);          // 0-1023
    analogSliderValues[i] = map(raw, 0, 1023, 0, 1000); // 0-1000
  }

  // Read digital buttons (INPUT_PULLUP means LOW when pressed, so we invert it)
  for (int i = 0; i < NUM_BUTTONS; i++) {
    // 1 when pressed, 0 when released
    buttonValues[i] = !digitalRead(buttonInputs[i]);
  }
}


// --- DATA TRANSMISSION FUNCTIONS ---

// Sends all slider data on a single line continuously.
// Format: Slider 1 512|Slider 2 1023|...
void sendContinuousSliderValues() {
  String builtString = "";

  // Append Slider Values (Slider 1, Slider 2, Slider 3, etc.)
  for (int i = 0; i < NUM_SLIDERS; i++) {
    builtString += "Slider ";
    builtString += String(i + 1);
    builtString += " "; // Space is part of the required format
    builtString += String(analogSliderValues[i]);

    // Add separator only if it's not the last slider
    if (i < NUM_SLIDERS - 1) {
      builtString += "|";
    }
  }

  // Only print if there are sliders defined
  if (NUM_SLIDERS > 0) {
    Serial.println(builtString);
  }
}


// Checks for a press event (0 -> 1 transition) on any button and sends a separate line.
// This implements the one-shot press logic with debouncing.
void checkAndSendButtonEvents() {
  unsigned long now = millis();
  
  for (int i = 0; i < NUM_BUTTONS; i++) {
    int current = buttonValues[i];
    int previous = previousButtonValues[i];

    // Check for a RISING EDGE (button just pressed: 0 -> 1)
    if (current == 1 && previous == 0) {
      // Check debounce interval to prevent switch bounce
      if (now - lastButtonChange[i] > DEBOUNCE_MS) {
        // Button was just pressed (and debounced). Send event: Button X 1
        String eventString = "Button ";
        eventString += String(i + 1);
        eventString += " 1";
        Serial.println(eventString);
        
        // Update last change time
        lastButtonChange[i] = now;
      }
      // Note: We only send the '1' event (press). The system is silent on release.
    }

    // Update the previous state for the next loop iteration.
    // This allows us to detect the next press only after the button has been released (current=0)
    previousButtonValues[i] = current;
  }
}

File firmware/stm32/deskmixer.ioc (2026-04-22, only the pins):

Mcu.UserName=STM32F103C8Tx
PA0-WKUP.Signal=ADCx_IN0
PA1.Signal=ADCx_IN1
PA11.Signal=USB_DM
PA12.Signal=USB_DP
PA13.Signal=SYS_JTMS-SWDIO
PA14.Signal=SYS_JTCK-SWCLK
PA2.Signal=ADCx_IN2
PA3.Signal=ADCx_IN3
PA4.Signal=ADCx_IN4
PA5.Signal=SPI1_SCK
PA6.Signal=SPI1_MISO
PA7.Signal=SPI1_MOSI
PB0.GPIO_Label=FLASH_CS
PB0.Signal=GPIO_Output
PB1.Signal=GPIO_Input
PB10.Signal=GPIO_Input
PB11.Signal=GPIO_Input
PB13.Signal=SPI2_SCK
PB15.Signal=SPI2_MOSI
PB2.Signal=GPIO_Input
PB3.Signal=GPIO_Input
PB4.Signal=GPIO_Input
PB6.Signal=I2C1_SCL
PB7.Signal=I2C1_SDA
PD0-OSC_IN.Signal=RCC_OSC_IN
PD1-OSC_OUT.Signal=RCC_OSC_OUT

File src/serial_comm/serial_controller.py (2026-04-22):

import threading
import time
from utils.error_handler import log_error
from audio.audio_utils import SliderSmoother
from serial_comm.data_parser import SerialDataParser
from utils.actions import ActionHandler

class SerialController:
    """
    Handles serial data processing, event dispatching, and action execution.
    Decouples serial logic from AudioManager.
    """

    def __init__(self, audio_manager, serial_handler, config_manager):
        self.audio_manager = audio_manager
        self.serial_handler = serial_handler
        self.config_manager = config_manager
        
        # Components
        self.slider_smoother = SliderSmoother()
        self.data_parser = SerialDataParser()
        self.action_handler = ActionHandler(audio_manager)
        
        # State tracking
        self.last_focused_app = None
        
        # Threshold tracking to prevent unnecessary volume calls
        self.last_applied_values = {}
        self.VOLUME_CHANGE_THRESHOLD = 0.01  # 1% threshold

    def start(self):
        """Start processing events and listening to serial"""
        if self.serial_handler:
            self.serial_handler.add_callback(self._handle_serial_data)
        print("SerialController started")

    def stop(self):
        """Stop processing and cleanup"""
        print("Stopping SerialController...")
        if self.serial_handler:
            self.serial_handler.remove_callback(self._handle_serial_data)


    def _handle_serial_data(self, data):
        """Handle incoming serial data"""
        try:
            # Parse data using the parser
            parsed_event = self.data_parser.parse_data(data)
            if not parsed_event:
                return

            # Handle Buttons - Execute Directly (no queue)
            if parsed_event.buttons:
                for btn_id, state in parsed_event.buttons.items():
                    if state: 
                        # Execute immediately in serial thread for lowest latency
                        self._handle_button_action(btn_id, state)

            # Handle Sliders - Direct Update
            if parsed_event.sliders and self.config_manager:
                # Use cached config - ConfigManager is singleton and updated by UI
                config = self.config_manager.config
                bindings = config.get('variable_bindings', {})
                slider_sampling = self.config_manager.get_slider_sampling()

                for slider_id, value in parsed_event.sliders.items():
                    # Apply smoothing
                    averaged_value = self.slider_smoother.apply_averaging(slider_id, value, slider_sampling)

                    # Skip threshold check in instant mode for zero latency
                    if slider_sampling == 'instant':
                        # Direct update - no threshold filtering
                        self.last_applied_values[slider_id] = averaged_value
                        binding = bindings.get(slider_id)
                        if binding:
                            self._apply_volume_change(binding, averaged_value)
                    else:
                        # Apply threshold to prevent excessive COM calls
                        last_value = self.last_applied_values.get(slider_id, -1)
                        if abs(averaged_value - last_value) >= self.VOLUME_CHANGE_THRESHOLD:
                            self.last_applied_values[slider_id] = averaged_value
                            
                            binding = bindings.get(slider_id)
                            if binding:
                                self._apply_volume_change(binding, averaged_value)

        except Exception as e:
            log_error(e, f"Error handling serial data: {data}")

    def apply_last_volumes(self):
        """Re-apply last known volumes to current audio device (used after device change)"""
        if not self.last_applied_values or not self.config_manager:
            return
            
        # Do not enforce volumes in the background if the hardware device is not connected
        if not self.serial_handler or not self.serial_handler.is_connected():
            return
            
        print("Syncing volumes to new device...")
        # Small delay to ensure Windows has fully switched the default device
        time.sleep(1.0)
        
        try:
            config = self.config_manager.config
            bindings = config.get('variable_bindings', {})
            
            for slider_id, value in self.last_applied_values.items():
                binding = bindings.get(slider_id)
                if binding:
                    # Force re-application
                    self._apply_volume_change(binding, value)
                    
        except Exception as e:
            log_error(e, "Error syncing volumes after device change")

    def _apply_volume_change(self, binding, value):
        """Apply volume change to targets"""
        if not self.audio_manager: return

        if isinstance(binding, dict):
            targets = binding.get('app_name', [])
        elif isinstance(binding, list):
            targets = binding
        else:
            targets = [binding] if binding else []

        if isinstance(targets, str):
            targets = [targets]

        for target in targets:
            # Handle new binding structure (list of dicts)
            if isinstance(target, dict):
                # Check for 'value' (new format) or 'app_name' (possible legacy/other format)
                target = target.get('value') or target.get('app_name')
            
            if not target:
                continue

            # Normalize target for case-insensitive comparison
            target_lower = target.lower()

            if target_lower == "master":
                self.audio_manager.set_master_volume(value)
            elif target_lower == "microphone":
                self.audio_manager.set_mic_volume(value)
            elif target_lower == "system sounds":
                self.audio_manager.set_system_sounds_volume(value)
            elif target_lower == "unbound":
                self.audio_manager.set_unbound_volumes(value)
            elif target_lower == "current application":
                self._handle_current_application_volume(value)
            elif target_lower == "none":
                pass
            else:
                # For specific apps, use original case
                self.audio_manager.set_app_volume(target, value)
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

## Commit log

2025-10-23 Updated the requirements.txt file with new dependencies. Updated README.md to reflect recent changes. Added functionality for app bindings for buttons.
2025-10-23 Fixed a bug where if I changed the output device, the volume changes were done to the previous output.
2025-10-24 Implemented the function to detect device disconnection and automatic reconnection.
2025-10-26 Added the functionality to switch the audio output and changed the behaviour of the x button on the window to close the application not minimise. Added better com handling on audio manager.
2025-10-26 fixed a bug where a powershell was appearing during audio output switch
2025-10-27 Changed the behaviour of the connection to the device, it now tries to autoconnect to the device via handshake. And handles disconection and automatic reconection.
2025-10-28 Changed the save location of the config file and the error.log.
    [DeskMixer.ino, serial_handler.py]
2025-10-28 Added a button to open the config and log folder.
2025-10-28 Updated so when connected succesfully to a device saves that connection to the config.json.
2025-10-28 Changed the behaviour of the config tab, instead of manually creating the fields and assigning the variables it auto creates the fields and assigns the variable names. Fully adaptable to the configur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
2025-11-06 Removed the button for search, instead now it searches on clicking on the input field, and better shortcut handling.
2025-11-09 updated pycaw version to 20251023 and changed audio output switchng protocol from using audiodevicecmd to pycaw
2025-12-11 Audio controller optimisation and button handler smoothing. Ui optimisations.
2025-12-12 Optimize latency (~200ms reduction), fix action mappings, enhance mute menu
    [DeskMixer.ino, serial_controller.py]
2025-12-12 Fixed ui slider sync on launch with the board. Removed tkinter imports.
2025-12-17 Refactor MenuBuilder, Add Volume Sync & Screen Menu
    Changes:
    Refactor: Split
    MenuBuilder
    logic into dedicated SettingsMenu, SliderMenu, and
    ButtonMenu
    components in src/ui2/components/menu/.
    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
2026-04-22 Added gerber files, and created firmware for stm32. Changed the value parsing.
    [desk_mixer-B_Cu.gbr, desk_mixer-B_Mask.gbr, desk_mixer-B_Paste.gbr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]
2026-05-04 feat: implement STM32 slider ADC drivers, serial communication protocol, and Python interface for device data parsing and testing
2026-05-09 feat: implement SK6812 LED driver and animation system for DeskMixer firmware
2026-05-09 Improved parameter parsing and implemented partial led configurations
2026-05-10 Fixed led and oled slider based reading procentages and slider data sampler.
    [deskmixer.c, leds.c, sliders.c]
2026-05-17 implement board communication layer and expand STM32 firmware functionality
    [deskmixer.FCStd, deskmixer.blend]
